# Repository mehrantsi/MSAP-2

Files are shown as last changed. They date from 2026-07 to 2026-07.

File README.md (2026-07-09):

# MSAP-2

An 8-bit discrete-logic computer - the successor to [MSAP-1](https://github.com/mehrantsi/MSAP-1). Where MSAP-1 is a 256-byte SAP-1 derivative, MSAP-2 is a small but real computer: 8-bit variable-length opcodes driven by microcode in four 28C256 control ROMs, an 8KB address space split between a MOS operating-system ROM and user RAM, a hardware stack, vectored interrupts, a serial console, and an SD-card disk - programmable and usable entirely from its own terminal.

| Aspect | Description |
|---|---|
| Datapath | A, X (up/down counters), SP, 13-bit PC, hidden B operand register, 74HC181 ALU |
| Control | 32-bit control word from 4x 28C256, address = flags(3) \| opcode(8) \| step(4), 16 T-states/instruction max |
| Memory | 28C64 MOS ROM at `0x0000-0x0FFF`, HM6264 SRAM above; 13-bit MAR with a 4-way source mux and TMP+X index adder |
| Interrupts | IRQ pushes PC + flags and vectors through RAM at `0x1F1A`; BRK is a software breakpoint into the monitor |
| I/O | ACIA console (RX/TX status bits), SD disk with ready handshake, 7-seg display, 16-bit counter/comparator timer |
| Software | [MOS 1.1](https://github.com/mehrantsi/MOS-1) monitor (resident line assembler, disk filesystem, run-by-name) + EDIT, a disk-loaded editor/assembler with labels |

## Layout

- **[simulator/](simulator)** - the microcode-accurate simulator: 3D/2D bench, terminal, logic analyzer, oscilloscope, PSU model, microcode editor with EEPROM export, KiCad netlist/PCB export. `npm run dev` to run, `npm test` for the headless self-test that boots MOS and drives it end to end.
- **[Schematics/](Schematics)** - generated KiCad netlist and PCB files plus per-board schematic sheets (SVG/PNG), all derived from the simulator's module registry. See its README for the generation flow.
- The OS and EDIT live in [MOS-1](https://github.com/mehrantsi/MOS-1); the cross assembler (`msap-asm --isa msap2`) lives in [8-bit_CPU_Programmer](https://github.com/mehrantsi/8-bit_CPU_Programmer).

## Status

rev.A: the CPU executes from control-ROM images (no instruction logic outside them), the OS boots from a write-protected ROM image assembled by the real toolchain, every chip on every board carries declared pin nets, and both EEPROM sets (4 control ROMs + OS ROM) export as burnable binaries. Remaining before fabrication: route the exported PCB in KiCad and capture the rev.A schematic there from the netlist.

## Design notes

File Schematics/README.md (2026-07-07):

# MSAP-2 rev.A schematics

Everything in this folder is **generated from the simulator's module registry** (`../simulator/src/core/modules.ts`) - the same data the simulation, power model, and inspector run on. Nothing is drawn by hand, so the schematic can never drift from the machine that was verified.

## Files

- `MSAP-2 rev.A.net` - KiCad netlist: every component with footprint, every declared pin net, plus VCC/GND. Import into pcbnew via File > Import Netlist.
- `MSAP-2 rev.A.kicad_pcb` - single consolidated board, through-hole footprints, flow-packed by module with silkscreen labels and net assignments. **Unrouted** - this is the layout starting point.
- `MSAP-2 rev.A SMD.kicad_pcb` - the same board with SMD-equivalent footprints (SOIC/SOT).
- `KiCad/` - one `.kicad_sch` per board (KiCad 7+): every component as a symbol with its real pin count, nets attached as global labels at the pin tips. Open directly in eeschema, or plot from there.
- `SVG/`, `PNGs/` - one sheet per board (clock, PC, registers, stack pointer, ALU, RAM/ROM, control, terminal+disk IO, display, address path), rendered by the simulator's schematic view with routed same-net wires, in the classic KiCad light theme.

## Regenerating

`node scripts/export-schematics.mjs` in `../simulator` regenerates the netlist and both PCB variants after any registry change; the in-app Export menu produces the same files interactively. The per-board sheets come from the app's Schematic view (the SVGs are its exact render). The EEPROM contents (4x control ROM `.bin` from the Microcode panel, `mos.bin` / `ed.bin` from `~/dev/MOS-1/build.sh`) complete the burnable artifact set.

## Status vs MSAP-1

MSAP-1's `Schematics/` holds the hand-captured KiCad project for hardware that exists. MSAP-2 rev.A is the inverse flow: the registry is the source of truth, these files are its export, and the remaining manual steps before fabrication are routing the PCB and (optionally) capturing a hand-drawn `.kicad_sch` from the netlist for documentation.

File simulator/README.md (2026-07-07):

# MSAP-2 Simulator

The design workbench for MSAP-2: the successor to MSAP-1 with interrupts, a hardware stack, more registers, a richer ALU, an 8KB address space, a serial terminal, mass storage, and a resident operating system with a built-in line assembler and breakpoint debugging. Where the MSAP-1 simulator is a cycle-accurate digital twin of finished hardware, this is the opposite end of the workflow - a **microcode-accurate rev.A**: the CPU executes control words from four 28C256 ROM images, T-state by T-state, and boots the MOS 1.1 operating system from a 4KB ROM - the same artifacts (control ROMs + OS ROM) the hardware build will burn. The 3D bench, logic analyzer, oscilloscope, PSU, schematic editor, and KiCad export carry over from the MSAP-1 twin.

## Run

```
npm install
npm run dev        # open the printed URL
npm test           # headless self-test: boots MOS and drives it through the terminal
npm run build      # type-check + production build
```

## Architecture

| | MSAP-1 | MSAP-2 |
|---|---|---|
| Opcodes | 4-bit (16 slots) | 8-bit, variable-length instructions (1-3 bytes) |
| Memory | 16 bytes | 8 KB (13-bit addresses, HM6264 SRAM) |
| Registers | A, B, OUT | A, X, SP, PC(13), OUT |
| Flags | C, Z | C, Z, N, plus the interrupt-enable bit |
| Addressing | absolute only | immediate, absolute, indirect, indexed-X, port |
| Stack | - | 0x1Fxx page, SP starts at 0x1FFF and grows down (TXS relocates it) |
| Interrupts | - | IRQ vector with flag save/restore, EI/DI/RTI |
| I/O | 7-seg display | 5 ports: console in/out, disk, display, timer |

### Memory map

| Range | Use |
|---|---|
| `0x0000-0x0FFF` | MOS: reset vector at `0x0000`, IRQ vector at `0x0008`, BRK vector at `0x000B`, syscall jump table at `0x0010`, monitor code, messages, and the assembler tables |
| `0x1000-0x1EFF` | User program area (`R 1000`) - just under 4KB |
| `0x1F00-0x1F9F` | MOS variables, line buffer, disk command buffer |
| `0x1FA0-0x1FFF` | Stack (SP starts at `0xFF` = address `0x1FFF`, grows down; the monitor resets it with `TXS` at every prompt) |

### Interrupts

An IRQ pushes PC high, PC low, then the flags, disables interrupts, and jumps to `0x008`. `RTI` restores the flags and return address. `EI`/`DI` gate the whole mechanism. The timer (port 4) raises an IRQ every A x 256 cycles; the Ticks example hooks the vector and counts on the 7-segment display.

### I/O ports

| Port | Device |
|---|---|
| 0 | Console data - `IN` reads a key, `OUT` prints a character |
| 1 | Console status - bit 0: RX byte waiting, bit 1: TX ready (ACIA-style; poll bit 1 before OUT, mask bit 0 for input) |
| 2 | Smart disk - Arduino + SD card protocol (below) |
| 3 | 7-segment display |
| 4 | Timer - `OUT` with A=n fires an IRQ every n x 256 T-states, A=0 stops (161 counter chain + 688 comparator) |
| 5 | Disk status - 1 when the disk has finished the last command; poll before reading port 2 |

### Instruction set

Implied (1 byte): `NOP HLT EI DI RTS RTI PHA PLA PHX PLX TAX TXA TXS INX DEX SHL SHR BRK`

| Mnemonic | Modes | Notes |
|---|---|---|
| `LDA` | `#imm` `abs` `(ind)` `abs,x` | loads set Z/N |
| `STA` | `abs` `(ind)` `abs,x` | |
| `LDX` / `STX` | `#imm` `abs` / `abs` | |
| `ADD SUB AND ORA XOR CMP` | `#imm` `abs` | `CMP`/`SUB` set C = no borrow (A >= operand) |
| `CPX` | `#imm` | |
| `JMP JSR JZ JNZ JC JNC JN` | `abs` | two-byte little-endian addresses |
| `BRK` | - | pushes PC + flags and breaks into the monitor with a register dump |
| `IN` / `OUT` | `#port` | |

Assembler dialect: labels, `.org .byte .word .equ .ascii .asciiz`, `#` immediates, `<`/`>` lo/hi byte operators, `;` comments. The same dialect is spoken by the in-app assembler and by `msap-asm --isa msap2` in the 8-bit_CPU_Programmer repo (verified byte-for-byte in that repo's test suite).

## MOS 1.1

The resident monitor boots at reset, prints a banner, and takes commands from the terminal:

| Command | Action |
|---|---|
| `A AAAA` | assemble mode: type one instruction per line at the shown address, empty line ends |
| `D AAAA` | dump 32 bytes from hex address AAAA |
| `E AAAA BB ..` | enter bytes into memory |
| `R AAAA` or `R NAME` | run at an address, or load a file from disk and run it (bare `R` runs at `1000`) - `RTS` returns and prints A/X |
| `L NAME [AAAA]` | load a file from disk (default `1000`) |
| `S NAME AAAA NN` | save NN bytes from AAAA as NAME |
| `X NAME` | delete a file |
| `F` | list files |
| `H` | help |

Syscalls (stable jump table, safe to link against):

| Address | Call | Contract |
|---|---|---|
| `0x010` | PUTC | prints A |
| `0x013` | GETC | blocks, returns key in A |
| `0x016` | PUTS | prints the NUL-terminated string pointed to by `0x1F00/0x1F01` |
| `0x019` | GETLN | reads an edited line into `0x1F20`, NUL-terminated |
| `0x01C` | EXIT | returns to the monitor prompt |

The smart disk (port 2) mirrors the planned Arduino + SD card module: commands are NUL-terminated strings - `L NAME` answers length lo/hi (0xFFFF = not found) then the bytes, `S NAME` takes length then bytes, `F` streams a text listing, `D NAME` answers a status byte. In the simulator the filesystem persists in localStorage.

The assemble mode is a resident table-driven line assembler in the tradition of the Apple II mini-assembler: mnemonics with `#imm`, `abs`, `(ind)`, `abs,x` and port operands, all operands hex, no labels (the prompt shows the current address, so jumps use it directly). For breakpoints, put `BRK` anywhere in a program (opcode `37`): it stops, prints `BRK @AAAA A=.. X=..`, and returns to the prompt.

The disk boots pre-loaded with the example programs (`F` lists HELLO, ECHO, SHOUT, TICKS - `L SHOUT` then `R 1000` runs one). The MOS source lives in its own repo, `~/dev/MOS-1` - about 2.4KB assembled, well inside its 4KB ROM. The simulator loads the built `mos-rom.json` binary; `MOS-1/build.sh` reassembles it with `msap-asm` and refreshes the image.

## Using it

- **Terminal panel**: click it and type; keys feed port 0 and the clock auto-starts. The default clock is 20 kHz so the OS feels interactive (slider goes to 500 kHz); drag it down to watch the polling loop in the logic analyzer.
- **Program panel**: the examples (Hello, Echo, Shout, Ticks) assemble into the user area and *merge* into RAM without resetting, so MOS keeps running - load one, then type `R 1000`.
- **Inspector**: PC/A/X/SP/flags live view, RAM browser with a 256-byte pager (or follow-PC), power estimate, and part datasheets.
- Everything else - scope probes on chip pins, PSU limits, schematic editing with the design overlay, KiCad netlist/PCB export, per-panel maximize and persistence - works as in the MSAP-1 simulator.

## Microcode

The core executes T-state by T-state **from four 28C256 control-ROM images** - there is no instruction logic in TypeScript. `src/core/ucode.ts` defines the 32-bit control word (bus-source field, register strobes, MAR source mux, counter ops, ALU function, sequencer bits) and the microprogram for every opcode; `buildRoms()` expands it across the 8 flag banks (address = flags(3) | opcode(8) | step(4)), and `machine.stepT()` decodes one word per clock: drive the bus, latch the strobes, count, reset or advance the step counter. Conditional jumps are flag-banked ROM rows, interrupts are a forced opcode slot (0xFF), and BRK is an ordinary microprogram. The **Microcode panel** edits the control words live (with a boot check) and exports the four EEPROM .bin images for burning.

The OS is not part of the simulator: it lives in `~/dev/MOS-1`, is assembled by the real `msap-asm` toolchain, and the simulator boots the resulting binary from a write-protected 4KB ROM region - the same image a 28C64 would hold. Programs run through a RAM trampoline and interrupts hook a RAM vector, so nothing depends on writable ROM.

## Timing budget

One T-state must cover the longest path: step counter -> control ROM (150 ns) -> strobe gating -> source drive + RAM/ROM access (100-150 ns) -> latch setup. With standard 150 ns EEPROMs that is roughly 450-500 ns, so **~2 MHz** is the honest ceiling the slider allows; 70 ns ROMs and 55 ns SRAM on a PCB push toward 4-5 MHz. The console TX takes 80 T-states per character and the disk raises its ready bit ~512 T-states after a command - MOS polls both, so the same binary runs at any clock.

## Self-test

`npm test` assembles the OS, boots a headless machine, and drives it through the terminal: banner and help, `E`/`D` roundtrip, the resident assembler (including every addressing mode and error recovery), `BRK` breakpoints, the register dump on `RTS`, the seeded disk, all four examples (including the interrupt-driven Ticks), save/list/load/delete, stack discipline with `TXS`, and indirect/indexed addressing.

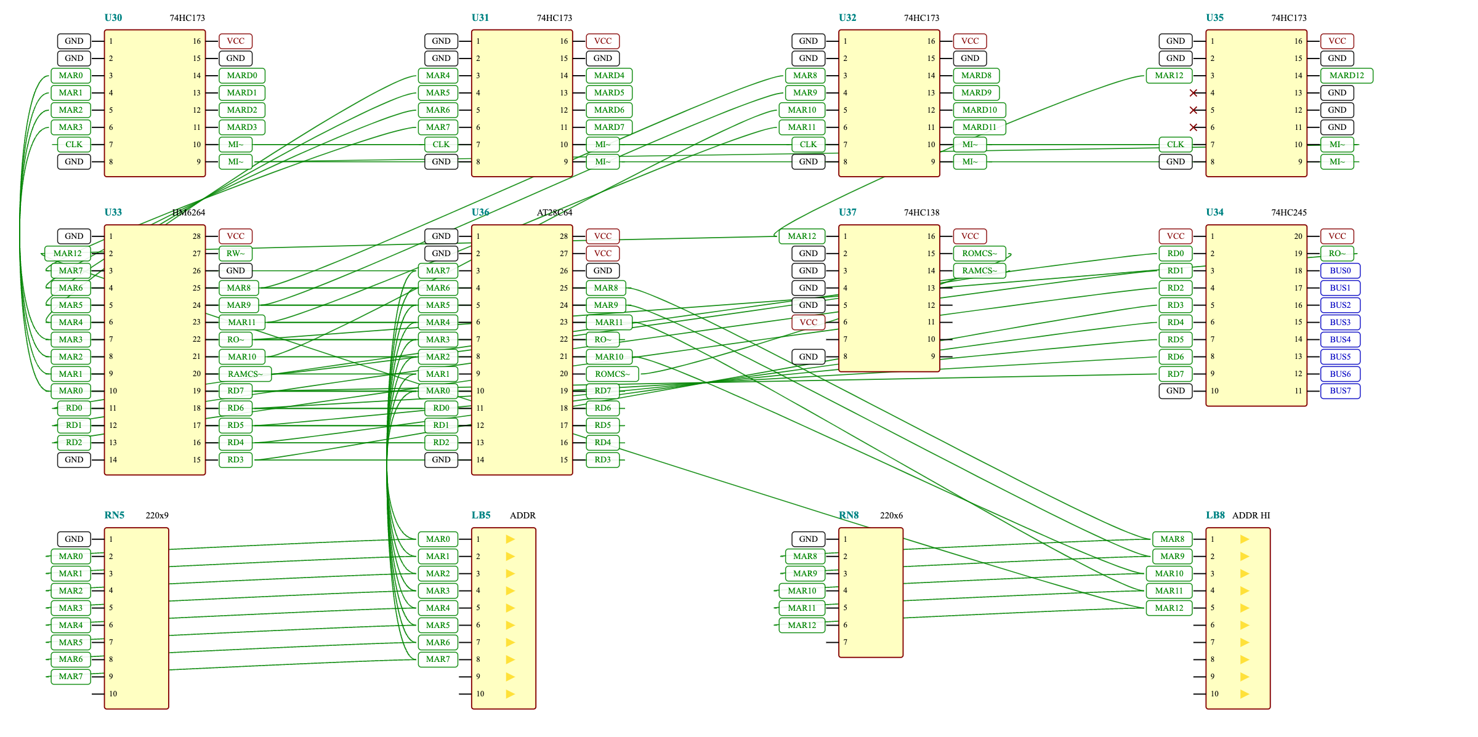
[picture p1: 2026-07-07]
Schematics/PNGs/RAM_8KB.png

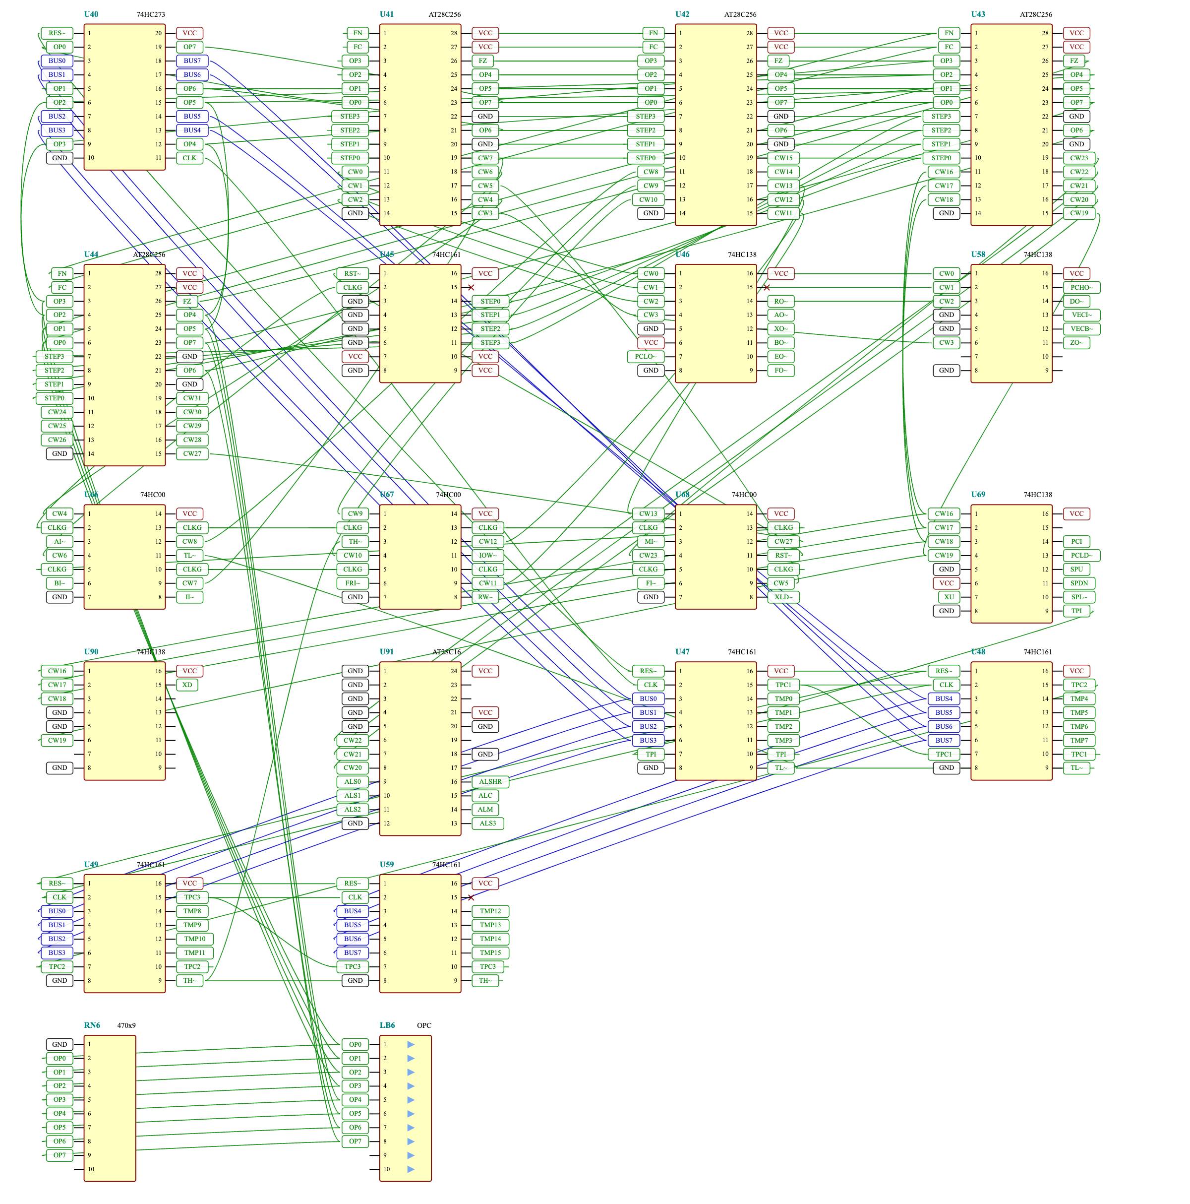
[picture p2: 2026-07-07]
Schematics/PNGs/CONTROL_4x28C256.png

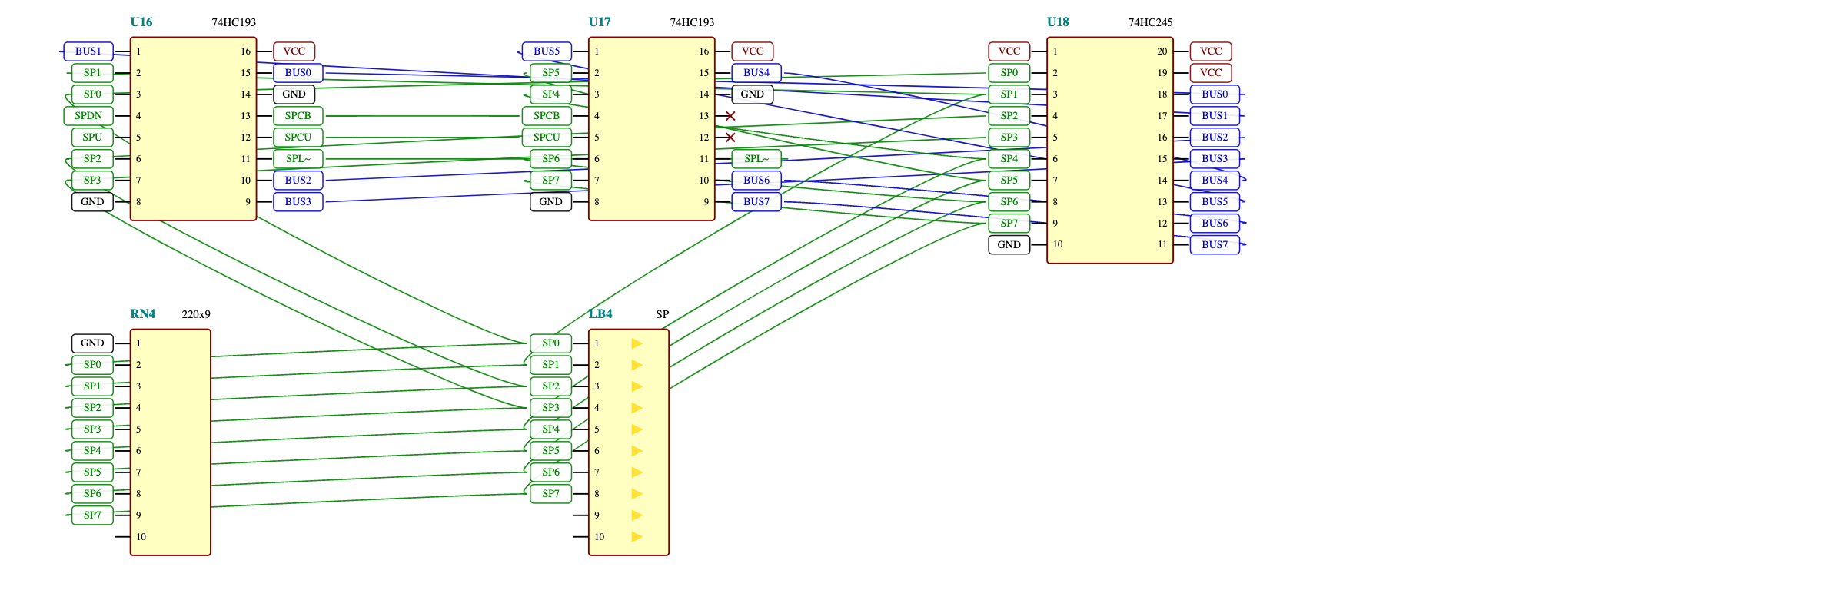
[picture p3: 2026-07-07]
Schematics/PNGs/STACK_POINTER.png

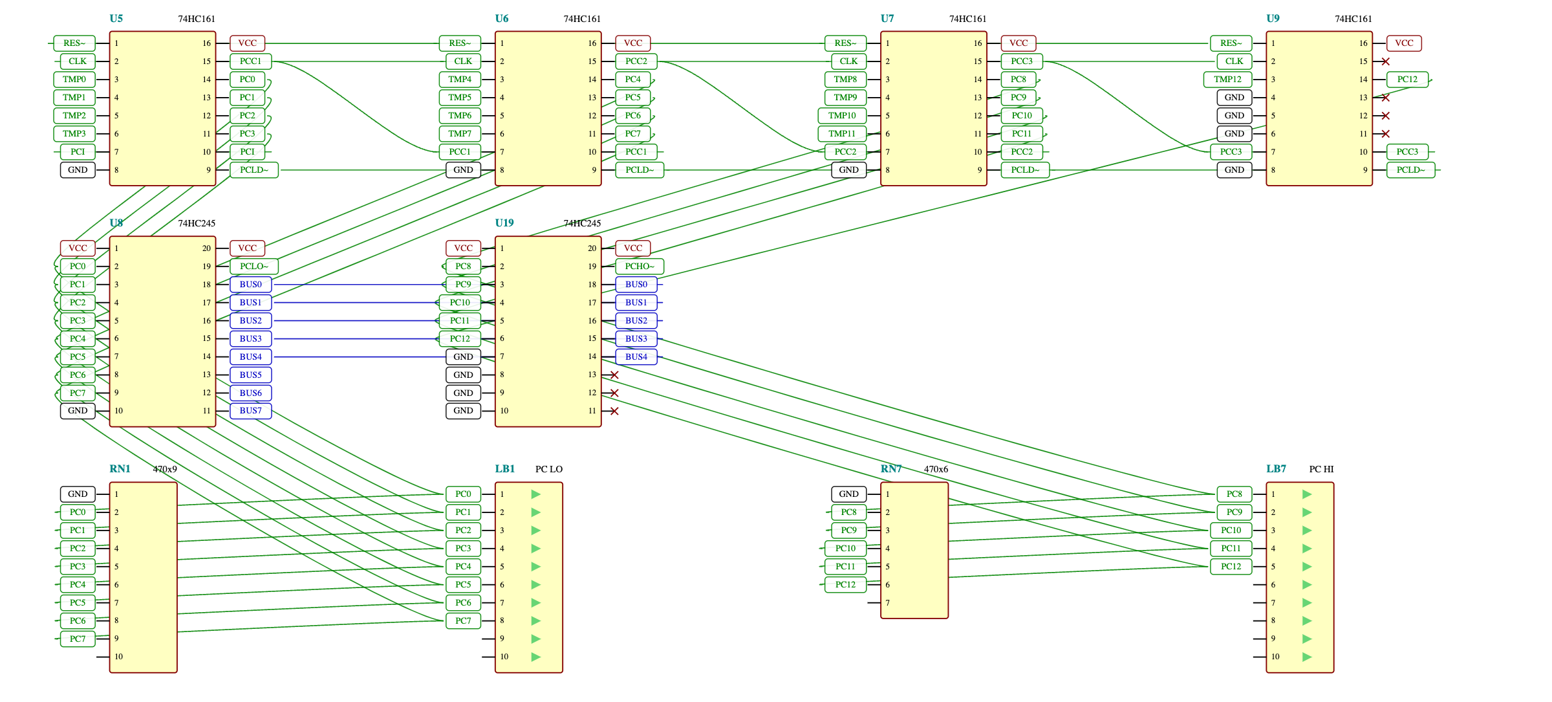
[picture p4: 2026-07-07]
Schematics/PNGs/PROGRAM_COUNTER_13B.png

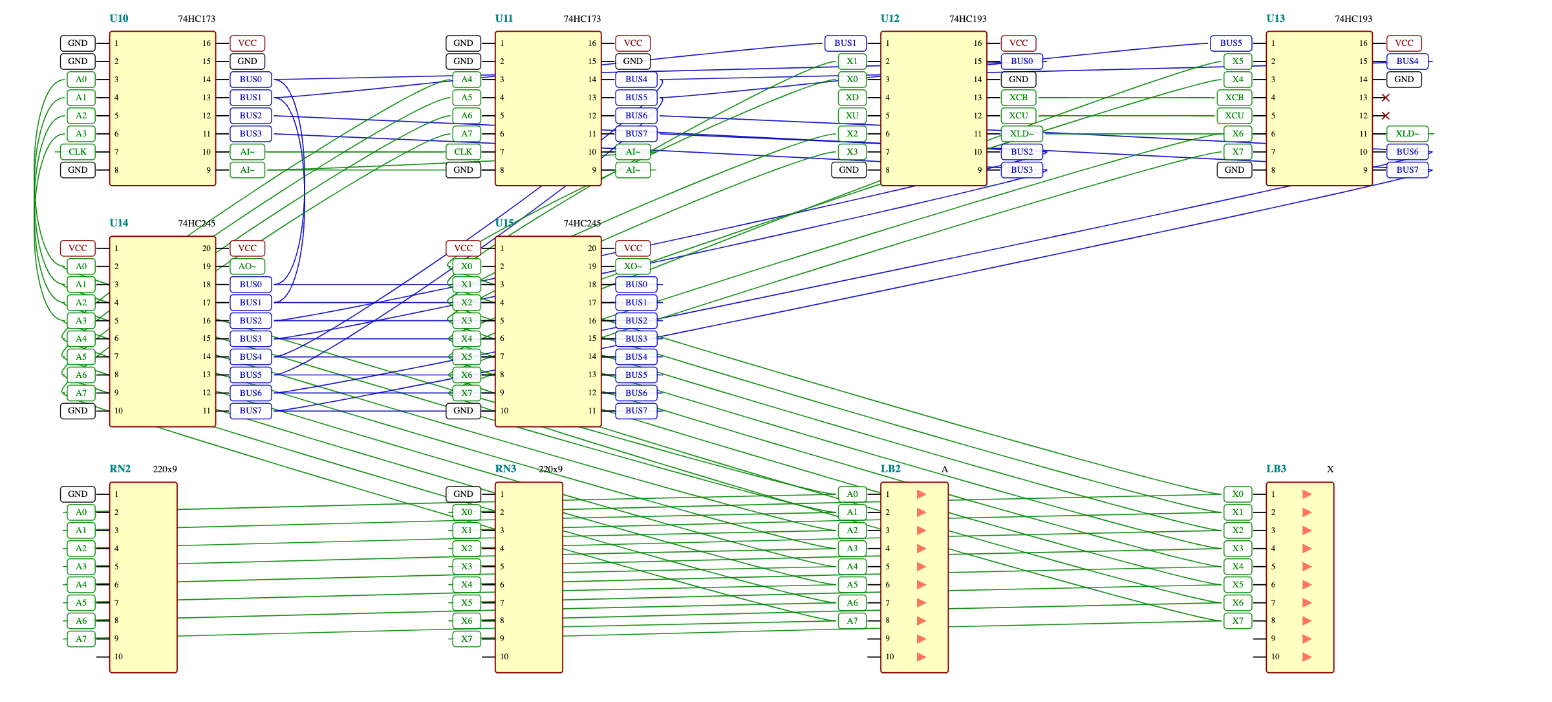
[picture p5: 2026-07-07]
Schematics/PNGs/A_X_REGISTERS.png

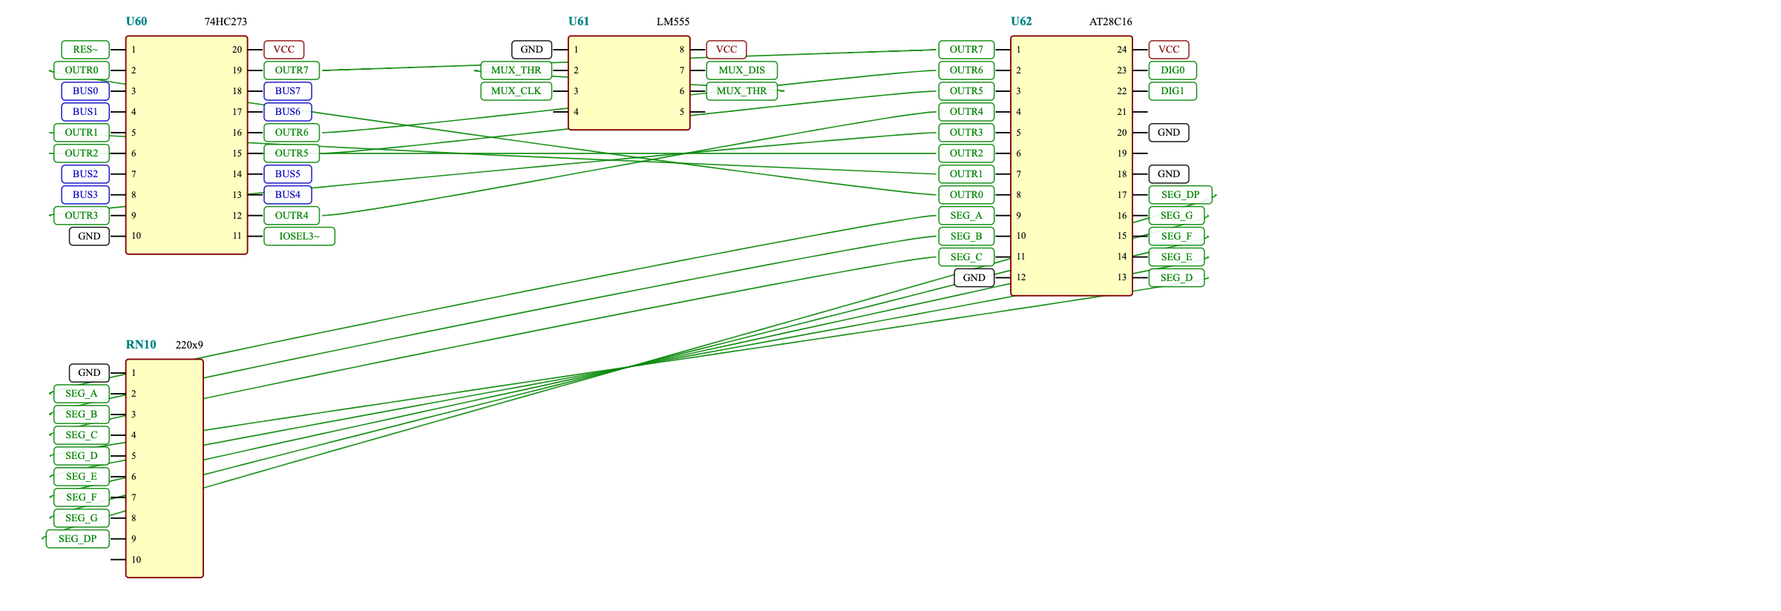
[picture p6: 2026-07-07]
Schematics/PNGs/DISPLAY.png

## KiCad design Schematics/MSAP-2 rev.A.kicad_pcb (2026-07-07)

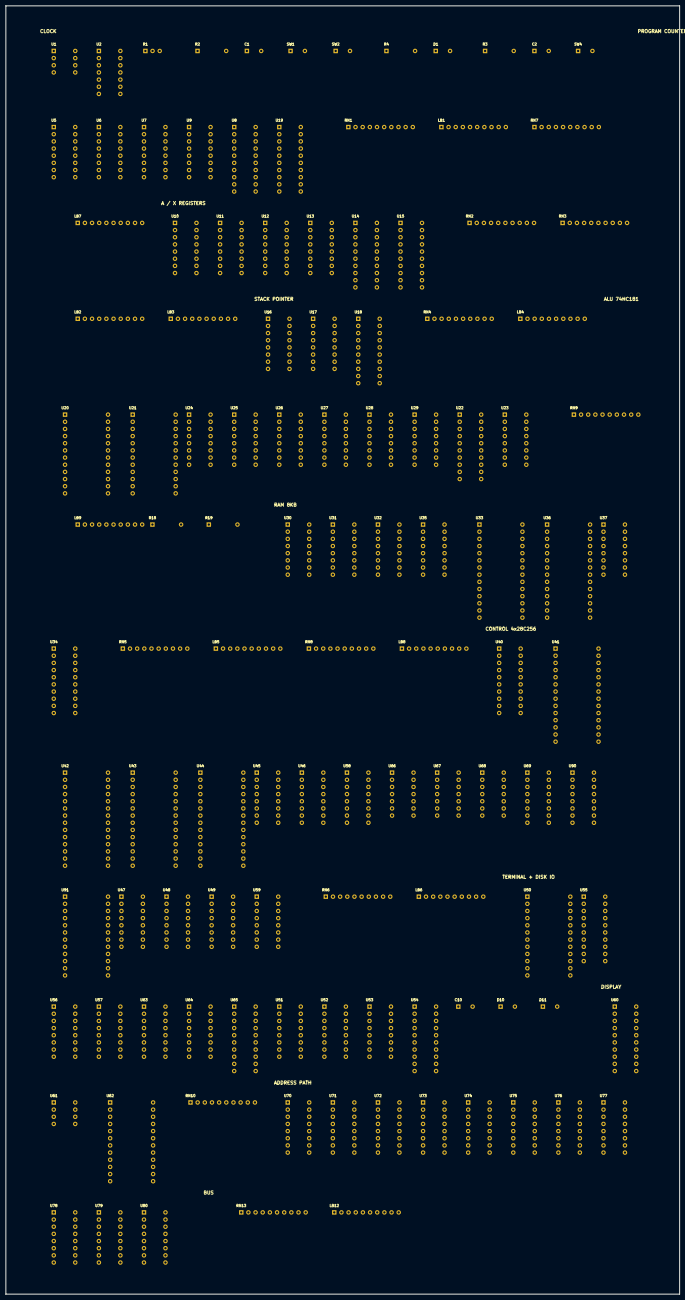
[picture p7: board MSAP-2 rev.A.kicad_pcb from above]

Board: 2 copper layers, 239.0 x 457.0 mm, 114 parts (0 on the bottom side), 271 nets, no tracks yet.

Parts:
C1: 10nF; C_Disc_D5.0mm_W2.5mm_P5.00mm
C2: 10uF; C_Disc_D5.0mm_W2.5mm_P5.00mm
C10: 100nF; C_Disc_D5.0mm_W2.5mm_P5.00mm
D1: clk; LED_D3.0mm
D10: rx; LED_D3.0mm
D11: tx; LED_D3.0mm
LB1: PC LO; DIP-20_W7.62mm
LB2: A; DIP-20_W7.62mm
LB3: X; DIP-20_W7.62mm
LB4: SP; DIP-20_W7.62mm
LB5: ADDR; DIP-20_W7.62mm
LB6: OPC; DIP-20_W7.62mm
LB7: PC HI; DIP-20_W7.62mm
LB8: ADDR HI; DIP-20_W7.62mm
LB9: FLAGS; DIP-20_W7.62mm
LB12: BUS; DIP-20_W7.62mm
R1: 1M; Potentiometer_Bourns_3296W_Vertical
R2: 1K; R_Axial_DIN0207_L6.3mm_D2.5mm_P10.16mm_Horizontal
R3: 10K; R_Axial_DIN0207_L6.3mm_D2.5mm_P10.16mm_Horizontal
R4, R18, R19: 470; R_Axial_DIN0207_L6.3mm_D2.5mm_P10.16mm_Horizontal
RN1, RN6: 470x9; R_Array_SIP9
RN2, RN3, RN4, RN5, RN10, RN13: 220x9; R_Array_SIP9
RN7: 470x6; R_Array_SIP9
RN8: 220x6; R_Array_SIP9
RN9: 470x5; R_Array_SIP9
SW1: step; SW_PUSH_6mm_H5mm
SW2: mode; SW_PUSH_6mm_H5mm
SW4: reset; SW_PUSH_6mm_H5mm
U1, U61: LM555; DIP-8_W7.62mm
U2: 74HC14; DIP-14_W7.62mm
U5, U6, U7, U9, U45, U47, U48, U49, U56, U57, U59, U63, U64: 74HC161; DIP-16_W7.62mm
U8, U14, U15, U18, U19, U22, U34, U54: 74HC245; DIP-20_W7.62mm
U10, U11, U23, U24, U25, U30, U31, U32, U35: 74HC173; DIP-16_W7.62mm
U12, U13, U16, U17: 74HC193; DIP-16_W7.62mm
U20, U21: 74HC181; DIP-24_W15.24mm
U26, U27, U28, U29: 74HC157; DIP-16_W7.62mm
U33: HM6264; DIP-28_W15.24mm
U36: AT28C64; DIP-28_W15.24mm
U37, U46, U51, U58, U69, U90: 74HC138; DIP-16_W7.62mm
U40, U55, U60: 74HC273; DIP-20_W7.62mm
U41, U42, U43, U44: AT28C256; DIP-28_W15.24mm
U50: MC6850; DIP-24_W15.24mm
U52: 74HC595; DIP-16_W7.62mm
U53: 74HC165; DIP-16_W7.62mm
U62, U91: AT28C16; DIP-24_W15.24mm
U65: 74HC688; DIP-20_W7.62mm
U66, U67, U68: 74HC00; DIP-14_W7.62mm
U70, U71, U72, U73, U74, U75, U76: 74HC153; DIP-16_W7.62mm
U77, U78, U79, U80: 74HC283; DIP-16_W7.62mm

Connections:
555_DIS: R1.1, R2.2, U1.7
555_OUT: U1.3, U2.1
555_THR: C1.1, R1.2, U1.2, U1.6
A0: LB2.1, RN2.2, U10.3, U14.2, U28.2
A1: LB2.2, RN2.3, U10.4, U14.3, U28.5
A2: LB2.3, RN2.4, U10.5, U14.4, U28.14
A3: LB2.4, RN2.5, U10.6, U14.5, U28.11
A4: LB2.5, RN2.6, U11.3, U14.6, U29.2
A5: LB2.6, RN2.7, U11.4, U14.7, U29.5
A6: LB2.7, RN2.8, U11.5, U14.8, U29.14
A7: LB2.8, RN2.9, U11.6, U14.9, U29.11
AI~: U10.9, U10.10, U11.9, U11.10, U66.3
ALC: U20.7, U91.15
ALC4: U20.16, U21.7
ALCO: U21.16, U23.14
ALF0: U20.9, U26.2
ALF1: U20.10, U26.3, U26.5
ALF2: U20.11, U26.6, U26.14
ALF3: U20.13, U26.11, U26.13
ALF4: U21.9, U26.10, U27.2
ALF5: U21.10, U27.3, U27.5
ALF6: U21.11, U27.6, U27.14
ALF7: U21.13, U23.12, U27.11, U27.13
ALM: U20.8, U21.8, U91.14
ALO0: U22.2, U26.4
ALO1: U22.3, U26.7
ALO2: U22.4, U26.12
ALO3: U22.5, U26.9
ALO4: U22.6, U27.4
ALO5: U22.7, U27.7
ALO6: U22.8, U27.12
ALO7: U22.9, U27.9
ALS0: U20.6, U21.6, U91.9
ALS1: U20.5, U21.5, U91.10
ALS2: U20.4, U21.4, U91.11
ALS3: U20.3, U21.3, U91.13
ALSHR: U26.1, U27.1, U91.16
AO~: U14.19, U46.13
AS0: U20.2, U28.4
AS1: U20.23, U28.7
AS2: U20.21, U28.12
AS3: U20.19, U28.9
AS4: U21.2, U29.4
AS5: U21.23, U29.7
AS6: U21.21, U29.12
AS7: U21.19, U29.9
AXS: U28.1, U29.1
B0: U20.1, U24.3
B1: U20.22, U24.4
B2: U20.20, U24.5
B3: U20.18, U24.6
B4: U21.1, U25.3
B5: U21.22, U25.4
B6: U21.20, U25.5
B7: U21.18, U25.6
BI~: U24.9, U24.10, U25.9, U25.10, U66.6
BUS0: LB12.1, RN13.2, U8.18, U10.14, U12.15, U14.18, U15.18, U16.15, U18.18, U19.18, U22.18, U24.14, U34.18, U40.3, U47.3, U49.3, U50.22, U54.18, U55.3, U60.3
BUS1: LB12.2, RN13.3, U8.17, U10.13, U12.1, U14.17, U15.17, U16.1, U18.17, U19.17, U22.17, U24.13, U34.17, U40.4, U47.4, U49.4, U50.21, U54.17, U55.4, U60.4
BUS2: LB12.3, RN13.4, U8.16, U10.12, U12.10, U14.16, U15.16, U16.10, U18.16, U19.16, U22.16, U24.12, U34.16, U40.7, U47.5, U49.5, U50.20, U54.16, U55.7, U60.7
BUS3: LB12.4, RN13.5, U8.15, U10.11, U12.9, U14.15, U15.15, U16.9, U18.15, U19.15, U22.15, U24.11, U34.15, U40.8, U47.6, U49.6, U50.19, U54.15, U55.8, U60.8
BUS4: LB12.5, RN13.6, U8.14, U11.14, U13.15, U14.14, U15.14, U17.15, U18.14, U19.14, U22.14, U25.14, U34.14, U40.13, U48.3, U50.18, U54.14, U55.13, U59.3, U60.13
BUS5: LB12.6, RN13.7, U8.13, U11.13, U13.1, U14.13, U15.13, U17.1, U18.13, U22.13, U25.13, U34.13, U40.14, U48.4, U50.17, U54.13, U55.14, U59.4, U60.14
BUS6: LB12.7, RN13.8, U8.12, U11.12, U13.10, U14.12, U15.12, U17.10, U18.12, U22.12, U25.12, U34.12, U40.17, U48.5, U50.16, U54.12, U55.17, U59.5, U60.17
BUS7: LB12.8, RN13.9, U8.11, U11.11, U13.9, U14.11, U15.11, U17.9, U18.11, U22.11, U25.11, U34.11, U40.18, U48.6, U50.15, U54.11, U55.18, U59.6, U60.18
CLK: R4.1, U2.2, U2.9, U5.2, U6.2, U7.2, U9.2, U10.7, U11.7, U23.7, U24.7, U25.7, U30.7, U31.7, U32.7, U35.7, U40.11, U47.2, U48.2, U49.2, U50.14, U56.2, U57.2, U59.2, U63.2, U64.2
CLKG: U2.8, U45.2, U66.2, U66.5, U66.10, U66.13, U67.2, U67.5, U67.10, U67.13, U68.2, U68.5, U68.10, U68.13
CW0: U41.11, U46.1, U58.1
CW1: U41.12, U46.2, U58.2
CW2: U41.13, U46.3, U58.3
CW3: U41.15, U46.4, U58.6
CW4: U41.16, U66.1
CW5: U41.17, U68.9
CW6: U41.18, U66.4
CW7: U41.19, U66.9
CW8: U42.11, U66.12
CW9: U42.12, U67.1
CW10: U42.13, U67.4
CW11: U42.15, U67.9
CW12: U42.16, U67.12
CW13: U42.17, U68.1
CW14: U42.18, U70.14, U71.14, U72.14, U73.14, U74.14, U75.14, U76.14
CW15: U42.19, U70.2, U71.2, U72.2, U73.2, U74.2, U75.2, U76.2
CW16: U43.11, U69.1, U90.1
CW17: U43.12, U69.2, U90.2
CW18: U43.13, U69.3, U90.3
CW19: U43.15, U69.4, U90.6
CW20: U43.16, U91.8
CW21: U43.17, U91.7
CW22: U43.18, U91.6
CW23: U43.19, U68.4
CW27: U44.15, U68.12
D1A: D1.1, R4.2
DO~: U54.19, U58.14
DSK_SCK: U52.11, U53.2
EO~: U22.19, U46.10
FC: LB9.1, RN9.2, U23.3, U41.2, U42.2, U43.2, U44.2
FIE: LB9.4, RN9.5, U23.6
FI~: U23.9, U23.10, U68.6
FN: LB9.3, RN9.4, U23.5, U41.1, U42.1, U43.1, U44.1
FZ: LB9.2, RN9.3, U23.4, U41.26, U42.26, U43.26, U44.26
GND: C1.2, C2.2, C10.2, D1.2, D10.2, D11.2, R18.2, R19.2, RN1.1, RN2.1, RN3.1, RN4.1, RN5.1, RN6.1, RN7.1, RN8.1, RN9.1, RN10.1, RN13.1, SW1.2, SW2.2, SW4.2, U1.1, U2.7, U5.8, U6.8, U7.8, U8.10, U9.4, U9.5, U9.6, U9.8, U10.1, U10.2, U10.8, U10.15, U11.1, U11.2, U11.8, U11.15, U12.8, U12.14, U13.8, U13.14, U14.10, U15.10, U16.8, U16.14, U17.8, U17.14, U18.10, U19.7, U19.8, U19.9, U19.10, U20.12, U21.12, U22.10, U23.1, U23.2, U23.8, U23.15, U24.1, U24.2, U24.8, U24.15, U25.1, U25.2, U25.8, U25.15, U26.8, U26.15, U27.8, U27.10, U27.15, U28.8, U28.15, U29.8, U29.15, U30.1, U30.2, U30.8, U30.15, U31.1, U31.2, U31.8, U31.15, U32.1, U32.2, U32.8, U32.15, U33.1, U33.14, U33.26, U34.10, U35.1, U35.2, U35.8, U35.11, U35.12, U35.13, U35.15, U36.1, U36.2, U36.14, U36.26, U37.2, U37.3, U37.4, U37.5, U37.8, U40.10, U41.14, U41.20, U41.22, U42.14, U42.20, U42.22, U43.14, U43.20, U43.22, U44.14, U44.20, U44.22, U45.3, U45.4, U45.5, U45.6, U45.8, U46.5, U46.8, U47.8, U48.8, U49.8, U50.1, U50.9, U51.4, U51.5, U51.8, U52.8, U52.13, U53.8, U53.15, U54.10, U55.10, U56.3, U56.4, U56.5, U56.6, U56.8, U57.3, U57.4, U57.5, U57.6, U57.8, U58.4, U58.5, U58.8, U59.8, U60.10, U61.1, U62.12, U62.18, U62.20, U63.3, U63.4, U63.5, U63.6, U63.8, U64.3, U64.4, U64.5, U64.6, U64.8, U65.1, U65.10, U66.7, U67.7, U68.7, U69.5, U69.8, U70.1, U70.8, U70.15, U71.1, U71.8, U71.15, U72.1, U72.8, U72.15, U73.1, U73.8, U73.15, U74.1, U74.8, U74.15, U75.1, U75.8, U75.15, U76.1, U76.8, U76.10, U76.11, U76.12, U76.13, U76.15, U77.7, U77.8, U78.8, U79.2, U79.6, U79.8, U79.11, U79.15, U80.2, U80.6, U80.8, U80.11, U80.15, U90.4, U90.5, U90.8, U91.1, U91.2, U91.3, U91.4, U91.5, U91.12, U91.18, U91.20
IOSEL0~: U50.10, U51.15
IOSEL3~: U51.12, U60.11
IOSEL4~: U51.11, U55.11
IOW: D11.1, U50.3
IOW~: U50.13, U67.11
MAR0: LB5.1, RN5.2, U30.3, U33.10, U36.10, U70.7
MAR1: LB5.2, RN5.3, U30.4, U33.9, U36.9, U70.9
MAR2: LB5.3, RN5.4, U30.5, U33.8, U36.8, U71.7
MAR3: LB5.4, RN5.5, U30.6, U33.7, U36.7, U71.9
MAR4: LB5.5, RN5.6, U31.3, U33.6, U36.6, U72.7
MAR5: LB5.6, RN5.7, U31.4, U33.5, U36.5, U72.9
MAR6: LB5.7, RN5.8, U31.5, U33.4, U36.4, U73.7
MAR7: LB5.8, RN5.9, U31.6, U33.3, U36.3, U73.9
MAR8: LB8.1, RN8.2, U32.3, U33.25, U36.25, U74.7
MAR9: LB8.2, RN8.3, U32.4, U33.24, U36.24, U74.9
MAR10: LB8.3, RN8.4, U32.5, U33.21, U36.21, U75.7
MAR11: LB8.4, RN8.5, U32.6, U33.23, U36.23, U75.9
MAR12: LB8.5, RN8.6, U33.2, U35.3, U37.1, U76.7
MI~: U30.9, U30.10, U31.9, U31.10, U32.9, U32.10, U35.9, U35.10, U68.3
MUX_THR: U61.2, U61.6
OP0: LB6.1, RN6.2, U40.2, U41.6, U42.6, U43.6, U44.6
OP1: LB6.2, RN6.3, U40.5, U41.5, U42.5, U43.5, U44.5
OP2: LB6.3, RN6.4, U40.6, U41.4, U42.4, U43.4, U44.4
OP3: LB6.4, RN6.5, U40.9, U41.3, U42.3, U43.3, U44.3
OP4: LB6.5, RN6.6, U40.12, U41.25, U42.25, U43.25, U44.25
OP5: LB6.6, RN6.7, U40.15, U41.24, U42.24, U43.24, U44.24
OP6: LB6.7, RN6.8, U40.16, U41.21, U42.21, U43.21, U44.21
OP7: LB6.8, RN6.9, U40.19, U41.23, U42.23, U43.23, U44.23
OUTR0: U60.2, U62.8
OUTR1: U60.5, U62.7
OUTR2: U60.6, U62.6
OUTR3: U60.9, U62.5
OUTR4: U60.12, U62.4
OUTR5: U60.15, U62.3
OUTR6: U60.16, U62.2
OUTR7: U60.19, U62.1
PC0: LB1.1, RN1.2, U5.14, U8.2, U70.6
PC1: LB1.2, RN1.3, U5.13, U8.3, U70.10
PC2: LB1.3, RN1.4, U5.12, U8.4, U71.6
PC3: LB1.4, RN1.5, U5.11, U8.5, U71.10
PC4: LB1.5, RN1.6, U6.14, U8.6, U72.6
PC5: LB1.6, RN1.7, U6.13, U8.7, U72.10
PC6: LB1.7, RN1.8, U6.12, U8.8, U73.6
PC7: LB1.8, RN1.9, U6.11, U8.9, U73.10
PC8: LB7.1, RN7.2, U7.14, U19.2, U74.6
PC9: LB7.2, RN7.3, U7.13, U19.3, U74.10
PC10: LB7.3, RN7.4, U7.12, U19.4, U75.6
PC11: LB7.4, RN7.5, U7.11, U19.5, U75.10
PC12: LB7.5, RN7.6, U9.14, U19.6, U76.6
PCC1: U5.15, U6.7, U6.10
PCC2: U6.15, U7.7, U7.10
PCC3: U7.15, U9.7, U9.10
PCHO~: U19.19, U58.15
PCI: U5.7, U5.10, U69.14
PCLD~: U5.9, U6.9, U7.9, U9.9, U69.13
PCLO~: U8.19, U46.7
RAMCS~: U33.20, U37.14
RD0: U33.11, U34.2, U36.11
RD1: U33.12, U34.3, U36.12
RD2: U33.13, U34.4, U36.13
RD3: U33.15, U34.5, U36.15
RD4: U33.16, U34.6, U36.16
RD5: U33.17, U34.7, U36.17
RD6: U33.18, U34.8, U36.18
RD7: U33.19, U34.9, U36.19
RESP: U2.4, U2.5
RES_RC: C2.1, R3.2, SW4.1, U2.3
RES~: U2.6, U5.1, U6.1, U7.1, U9.1, U40.1, U47.1, U48.1, U49.1, U55.1, U59.1, U60.1
ROMCS~: U36.20, U37.15
RO~: U33.22, U34.19, U36.22, U46.14
RST~: U45.1, U68.11
RW~: U33.27, U67.8
SEG_A: RN10.2, U62.9
SEG_B: RN10.3, U62.10
SEG_C: RN10.4, U62.11
SEG_D: RN10.5, U62.13
SEG_DP: RN10.9, U62.17
SEG_E: RN10.6, U62.14
SEG_F: RN10.7, U62.15
SEG_G: RN10.8, U62.16
SP0: LB4.1, RN4.2, U16.3, U18.2, U70.4
SP1: LB4.2, RN4.3, U16.2, U18.3, U70.12
SP2: LB4.3, RN4.4, U16.6, U18.4, U71.4
SP3: LB4.4, RN4.5, U16.7, U18.5, U71.12
SP4: LB4.5, RN4.6, U17.3, U18.6, U72.4
SP5: LB4.6, RN4.7, U17.2, U18.7, U72.12
SP6: LB4.7, RN4.8, U17.6, U18.8, U73.4
SP7: LB4.8, RN4.9, U17.7, U18.9, U73.12
SPCB: U16.13, U17.4
SPCU: U16.12, U17.5
SPDN: U16.4, U69.11
SPL~: U16.11, U17.11, U69.10
SPU: U16.5, U69.12
STEP0: U41.10, U42.10, U43.10, U44.10, U45.14
STEP1: U41.9, U42.9, U43.9, U44.9, U45.13
STEP2: U41.8, U42.8, U43.8, U44.8, U45.12
STEP3: U41.7, U42.7, U43.7, U44.7, U45.11
TCC1: U56.15, U57.7, U57.10
TCC2: U57.15, U63.7, U63.10
TCC3: U63.15, U64.7, U64.10
TCT8: U63.14, U65.2
TCT9: U63.13, U65.4
TCT10: U63.12, U65.6
TCT11: U63.11, U65.8
TCT12: U64.14, U65.11
TCT13: U64.13, U65.13
TCT14: U64.12, U65.15
TCT15: U64.11, U65.17
TH~: U49.9, U59.9, U67.3
TIRQ~: U56.1, U57.1, U63.1, U64.1, U65.19
TL~: U47.9, U48.9, U66.11
TMP0: U5.3, U47.14, U50.11, U51.1, U70.5, U77.5
TMP1: U5.4, U47.13, U51.2, U70.11, U77.3
TMP2: U5.5, U47.12, U51.3, U71.5, U77.14
TMP3: U5.6, U47.11, U71.11, U77.12
TMP4: U6.3, U48.14, U72.5, U78.5
TMP5: U6.4, U48.13, U72.11, U78.3
TMP6: U6.5, U48.12, U73.5, U78.14
TMP7: U6.6, U48.11, U73.11, U78.12
TMP8: U7.3, U49.14, U74.5, U79.5
TMP9: U7.4, U49.13, U74.11, U79.3
TMP10: U7.5, U49.12, U75.5, U79.14
TMP11: U7.6, U49.11, U75.11, U79.12
TMP12: U9.3, U59.14, U76.5, U80.5
TMP13: U59.13, U80.3
TMP14: U59.12, U80.14
TMP15: U59.11, U80.12
TPC1: U47.15, U48.7, U48.10
TPC2: U48.15, U49.7, U49.10
TPC3: U49.15, U59.7, U59.10
TPI: U47.7, U47.10, U69.9
TPR0: U55.2, U65.3
TPR1: U55.5, U65.5
TPR2: U55.6, U65.7
TPR3: U55.9, U65.9
TPR4: U55.12, U65.12
TPR5: U55.15, U65.14
TPR6: U55.16, U65.16
TPR7: U55.19, U65.18
TX0: U70.3, U77.4
TX1: U70.13, U77.1
TX2: U71.3, U77.13
TX3: U71.13, U77.10
TX4: U72.3, U78.4
TX5: U72.13, U78.1
TX6: U73.3, U78.13
TX7: U73.13, U78.10
TX8: U74.3, U79.4
TX9: U74.13, U79.1
TX10: U75.3, U79.13
TX11: U75.13, U79.10
TX12: U76.3, U80.4
TXC1: U77.9, U78.7
TXC2: U78.9, U79.7
TXC3: U79.9, U80.7
VCC: C10.1, R2.1, R3.1, U1.8, U2.14, U5.16, U6.16, U7.16, U8.1, U8.20, U9.16, U10.16, U11.16, U12.16, U13.16, U14.1, U14.20, U15.1, U15.20, U16.16, U17.16, U18.1, U18.19, U18.20, U19.1, U19.20, U20.24, U21.24, U22.1, U22.20, U23.16, U24.16, U25.16, U26.16, U27.16, U28.16, U29.16, U30.16, U31.16, U32.16, U33.28, U34.1, U34.20, U35.16, U36.27, U36.28, U37.6, U37.16, U40.20, U41.27, U41.28, U42.27, U42.28, U43.27, U43.28, U44.27, U44.28, U45.7, U45.9, U45.10, U45.16, U46.6, U46.16, U47.16, U48.16, U49.16, U50.8, U50.12, U51.6, U51.16, U52.10, U52.16, U53.16, U54.1, U54.20, U55.20, U56.7, U56.9, U56.10, U56.16, U57.9, U57.16, U58.16, U59.16, U60.20, U61.8, U62.24, U63.9, U63.16, U64.9, U64.16, U65.20, U66.14, U67.14, U68.14, U69.6, U69.16, U70.16, U71.16, U72.16, U73.16, U74.4, U74.12, U74.16, U75.4, U75.12, U75.16, U76.4, U76.16, U77.16, U78.16, U79.16, U80.16, U90.16, U91.21, U91.24
X0: LB3.1, RN3.2, U12.3, U15.2, U28.3, U77.6
X1: LB3.2, RN3.3, U12.2, U15.3, U28.6, U77.2
X2: LB3.3, RN3.4, U12.6, U15.4, U28.13, U77.15
X3: LB3.4, RN3.5, U12.7, U15.5, U28.10, U77.11
X4: LB3.5, RN3.6, U13.3, U15.6, U29.3, U78.6
X5: LB3.6, RN3.7, U13.2, U15.7, U29.6, U78.2
X6: LB3.7, RN3.8, U13.6, U15.8, U29.13, U78.15
X7: LB3.8, RN3.9, U13.7, U15.9, U29.10, U78.11
XCB: U12.13, U13.4
XCU: U12.12, U13.5
XD: U12.4, U90.15
XLD~: U12.11, U13.11, U68.8
XO~: U15.19, U46.12
XU: U12.5, U69.7
